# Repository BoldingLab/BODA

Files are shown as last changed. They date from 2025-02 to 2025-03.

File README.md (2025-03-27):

# BODA - Biosensor One-photon Data Acquisition

<p align="center">
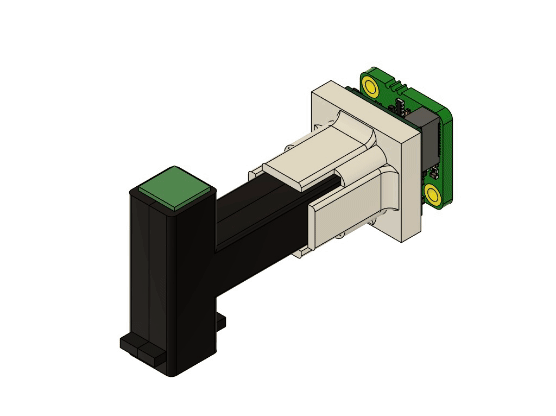
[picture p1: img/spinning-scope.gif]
Dual-Color Widefield Miniscope
  
</p>

## Overview

This repository contains design files, assembly instructions, and software for a high-resolution dual-color widefield miniscope optimized for fluorescence imaging in freely moving mice. The design features improved optical performance through the use of achromatic doublets and a refined optical path that provides:

- 2.45× magnification (increased from 0.9× in previous designs)
- 2.0mm minimum field of view
- Significantly reduced chromatic aberration
- Enhanced excitation light focusing
- Modular CMOS mount for flexible sensor options

## Repository Structure

```
.
├── assembly/               # Step-by-step assembly instructions
│   ├── Optical-Component-Assembly.md
│   ├── CMOS-Assembly.md
│   ├── LED-Installation.md
│   └── Resin-Print-Post-Processing.md
├── data-acquisition/       # Software for image acquisition
│   ├── data-acquisition.py
│   ├── DAC-README.md
│   └── Napari-Micromanager-DAC.md
├── img/                    # Images and figures
├── Optical-Analysis/       # Optical design analysis
│   ├── emission-system.ipynb
│   ├── excitation-system.ipynb
│   └── lens-data/
├── procurement/            # Bill of materials and sourcing information
└── README.md               # This file
```

## Optical Design

The miniscope uses a precisely calculated optical arrangement to achieve high-quality fluorescence imaging with minimal aberrations:

- **Emission Path**: Three achromatic doublets arranged to maximize resolution while maintaining a 2.0mm FOV
- **Excitation Path**: Two plano-convex lenses to optimize LED illumination
- **Filters**: 59022m emission filter and 59022x excitation filter, with a custom dichroic mirror

The design prioritizes:
1. High native resolution through increased magnification
2. Minimal chromatic aberration using achromatic doublets
3. Efficient excitation light delivery
4. Compact, lightweight form factor (under 4.5g)

## Assembly Process

Follow these steps to build your own miniscope:

1. **3D Printing**: Use the provided STL files to print the housing components using a high-resolution resin printer
2. **Post-Processing**: Clean and cure the printed parts following the [post-processing guide](assembly/Resin-Print-Post-Processing.md)
3. **Optical Assembly**: Install the optical components following the [optical assembly guide](assembly/Optical-Component-Assembly.md)
4. **LED Installation**: Set up the excitation system using the [LED installation guide](assembly/LED-Installation.md)
5. **CMOS Installation**: Prepare and install the camera module using the [CMOS assembly guide](assembly/CMOS-Assembly.md)

## Data Acquisition

Two options are provided for image acquisition:

1. **Simple Python GUI** - A lightweight application for controlling XIMEA cameras with features for:
   - Live viewing
   - Recording
   - Single frame capture
   - Adjustable exposure and downsampling

2. **Napari-Micromanager Integration** - A more advanced option providing:
   - Multi-dimensional acquisition
   - Integration with other microscopy hardware
   - Advanced image analysis capabilities

Setup and usage instructions can be found in the [data-acquisition](data-acquisition/) directory.

## Part Procurement

A complete list of components needed to build the miniscope can be found in the [procurement](procurement/) directory, including:
- Optical components
- Camera components
- Excitation components
- Housing components
- Assembly tools

## Optical Performance

This design offers significant improvements over previous miniscope implementations:
- **Magnification**: Increased from 0.9× to 2.45× (172% improvement)
- **Resolution**: Improved by 2.72× while maintaining a minimum 2.0mm FOV
- **Chromatic Aberration**: Reduced by >167%, eliminating the need to reposition when switching between red and green channels

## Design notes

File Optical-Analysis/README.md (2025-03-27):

# Dual-Color Widefield Miniscope Optical Design Overview

## I. Objective
Achieve the highest possible image quality in the dual-channel miniscope while maintaining a minimum field of view (FOV) of 2.0 millimeters.

## II. Methods
Various optical simulation software was developed in Python and used Zemax OpticStudio to simulate the optical components in the miniscope in order to optimize the optics configuration for the objective. Only one method of increasing native image resolution within the current system was determined to be feasible: Increasing the magnification of the miniscope. However, increasing the magnification of an optical system also comes with the caveat of decreasing the FOV of the optical system so a balance must be struck for the design.

To increase the magnification of the miniscope, the most important factors for increasing magnification are the distance between the object plane and the first lens of the system and the properties of the individual lenses.

Other than the resolution, another problem with the previous models of miniscope is the significant amount of noise and chromatic aberration in its images. The solution to mitigate most of the aberration issues is to replace the plano-convex lenses in the previous designs with doublets. Moreover, the image quality can also be improved by increasing the intensity of the excitation light due to its interaction with the fluorescence in the cells that the miniscope is designed to capture.

### External Constraints
There are four main external constraints for the miniscope that the optical system must also abide to:
- Weight of the miniscope
- Center of mass of the miniscope
- Availability of optical components
- Cost of optical components

Due to the fact that the miniscope is designed to mount the head of a mouse, the weight of the miniscope has to remain under 4.5 grams. As such, the optical components that are used for the miniscope must also account for this factor. Notably, lenses with an increased diameter exponentially increase the weight of the system due to the necessity of increasing the dimension of the entire miniscope housing to accommodate such a change. After experimentations with lenses with a diameter up to 9mm, it was concluded that using any optical component with a diameter above 6mm would make it extremely challenging to fulfill this constraint.

The center of mass of the miniscope must also be considered to account for how it might affect the mice that the miniscope will be mounted on. While this metric was never defined quantitatively during the duration of the project, it was determined that it would be too risky to have a "tall" miniscope where the emission portion of the miniscope is directly above the object plane, even if it would slightly improve the image quality by not requiring the image to be reflected. The availability of off-the-shelf lenses as well as the cost of each optical component was also considered during the design process to ensure that the miniscope can be replicated in the future at a reasonable cost.

## III. Final Design
After numerous tests with different simulations and designs, the miniscope design was finalized and the most notable changes from the original designs are:
- Replaced the plano-convex lenses with doublets
- Moved the initial lens directly above the object plane, placing it significantly closer than before
- Increased the magnification of the system
- Increased the intensity of the excitation light by increasing focus of the LED light
- Modularized the CMOS mount of the miniscope, allowing for different CMOS to be used for the same miniscope
- Removed one dichroic mirror from the design, mirroring the captured image as a side effect

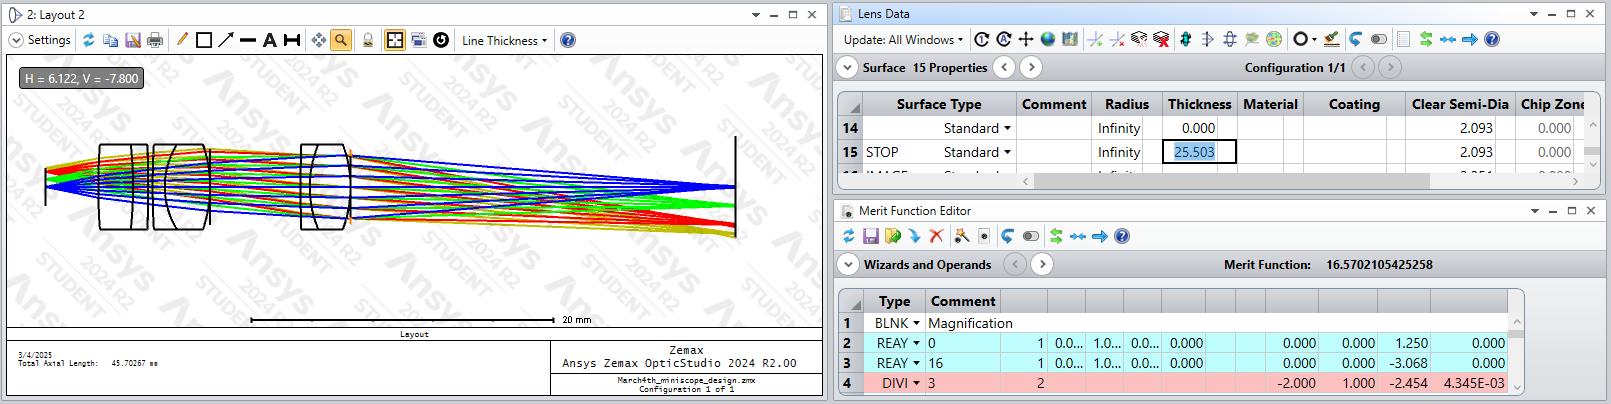
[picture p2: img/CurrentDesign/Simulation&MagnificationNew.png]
Figure 1: A simulation of the emission system of the miniscope in Zemax. The tables on the upper right lists each optical component within the system as well as the distance between. The table on the lower right showcases the magnification of the system.

Figure 1: A simulation of the emission system of the miniscope in Zemax. The tables on the upper right lists each optical component within the system as well as the distance between. The table on the lower right showcases the magnification of the system.
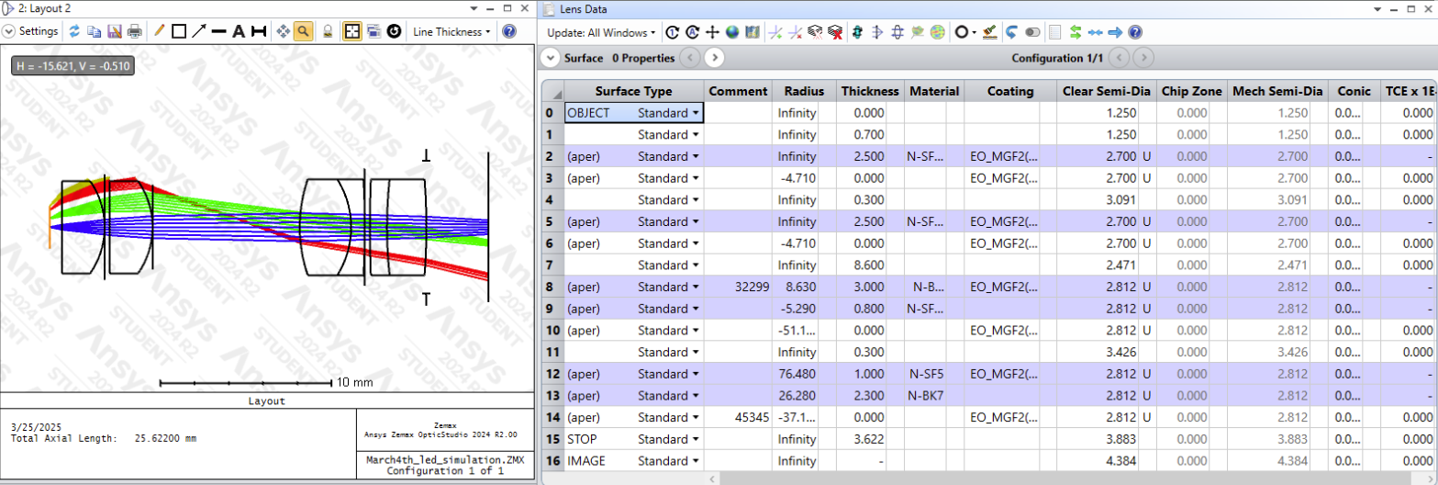
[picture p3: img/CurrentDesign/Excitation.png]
Figure 3: A simulation of the excitation system of the miniscope in Zemax. The tables on the upper right lists each optical component within the system as well as the distance between.

Figure 2: A simulation of the excitation system of the miniscope in Zemax. The tables on the upper right lists each optical component within the system as well as the distance between.
## IV. Results
The new design of the miniscope successfully achieved the objective of the project and tackled the numerous challenges the previous design had. The current design is able to produce higher quality images by improving the image resolution, reducing chromatic aberration, and increasing the effectiveness of excitation.

### Image Resolution
As mentioned above, image resolution directly correlates with the magnification of the system. By placing the lenses of the system closer to the object plane and selecting the proper lenses, the magnification of the optical system increased from 0.9x to 2.45x, resulting in a resolution increase and FOV decrease by the same magnitude of 2.72x theoretically (value obtained by dividing 2.45 by 0.9).

The theoretical magnification of the image is calculated using the "Merit Function Editor" function in Zemax, as seen in Figure 2. To calculate the magnification, the "REAY" values (y-coordinate of a simulated light ray) at the object and image plane were extracted, denoted by the values 0 and 15 respectively on the table. Afterwards, the values were divided by each other using the following equation to obtain the magnification.

```
Magnification = REAY_Image / REAY_Object
```

The logic behind the calculation being that as an image is being magnified, individual light rays will land farther from the center point than they were originally, resulting in every light ray spreading out from the center point and resulting in a larger image. By capturing the position of the rays, we can calculate how much an image is magnified by calculating how much it deviated from the original coordinate.

### Chromatic Aberration
By replacing the plano-convex lenses with doublets, the significant chromatic aberration issues that the previous design suffered from were also almost mostly mitigated. The most significant effect of this improvement is eliminating the need to reposition the y-axis of the miniscope when switching between red and green channels when performing the relevant experiments. This improvement allowed for both channels to be captured with high native resolution when it is placed in a fixed position atop a mouse.

<table>
  <tr>
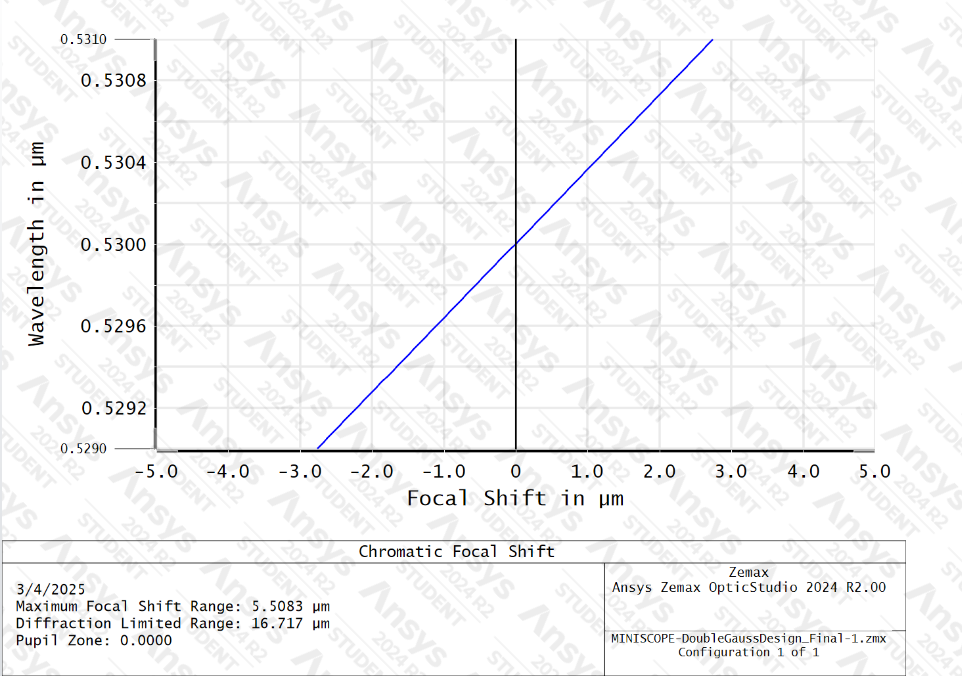
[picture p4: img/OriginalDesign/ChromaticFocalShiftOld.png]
    <td></td>
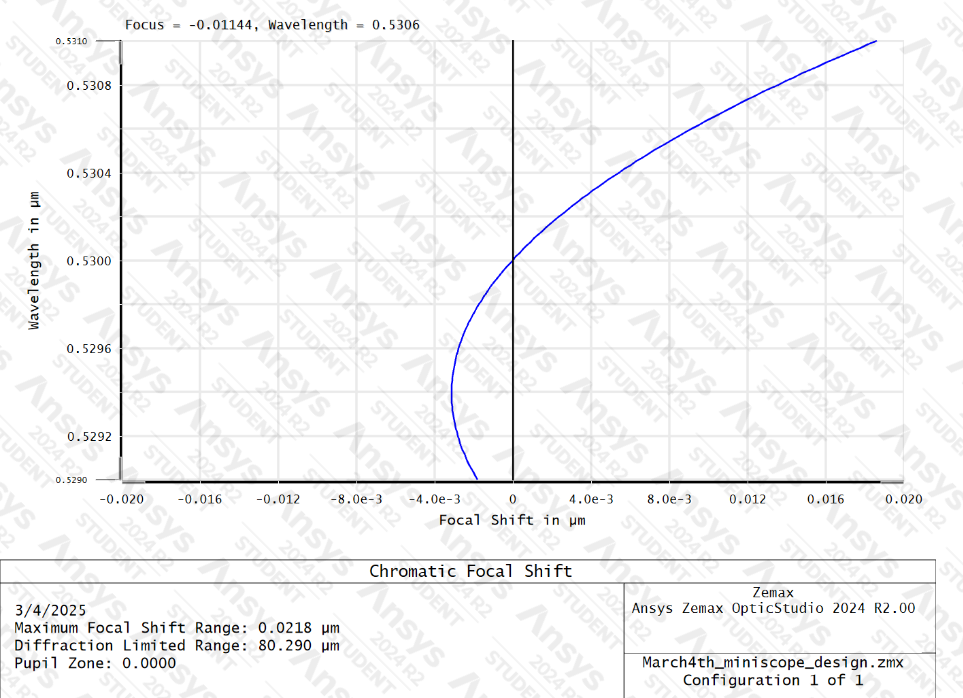
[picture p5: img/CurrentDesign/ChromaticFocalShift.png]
    <td></td>
  </tr>
</table>
Figure 4: Comparison of chromatic aberration between the old design (left) and the new design (right) in Zemax. The chromatic aberration of the new design is significantly reduced as seen in the values on the x-axis of the graphs.

As shown in the first graph representing the old design, the focal shift of the image linearly shifts roughly 1μm for every wavelength shift of 0.0004μm. Considering the peak wavelength of each channel has a difference of roughly 0.08μm, it would mean that that we would need to shift the y-coordinate of the miniscope by 0.08μm/0.0004μm = 200μm every time a channel is switched in the old design, which aligns with what was observed experimentally. By comparison, the same wavelength shift of 0.0004μm in the new design results in a focal shift of less than 0.006μm in a non-linear parabolic trend, essentially reducing the effect of the chromatic aberration by more than 167%.

However, it should be noted that the new design performs slightly worse in some of the other aberration tests in Zemax, in categories such as field curvature, grid distortion, longitude aberration etc.

<table>
  <tr>
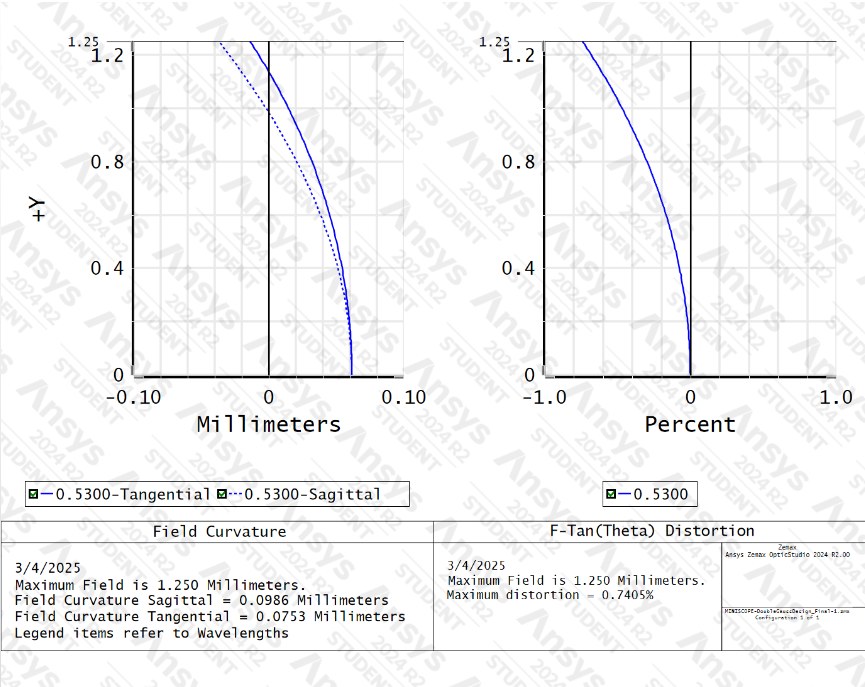
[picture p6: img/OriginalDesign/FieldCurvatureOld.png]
    <td></td>
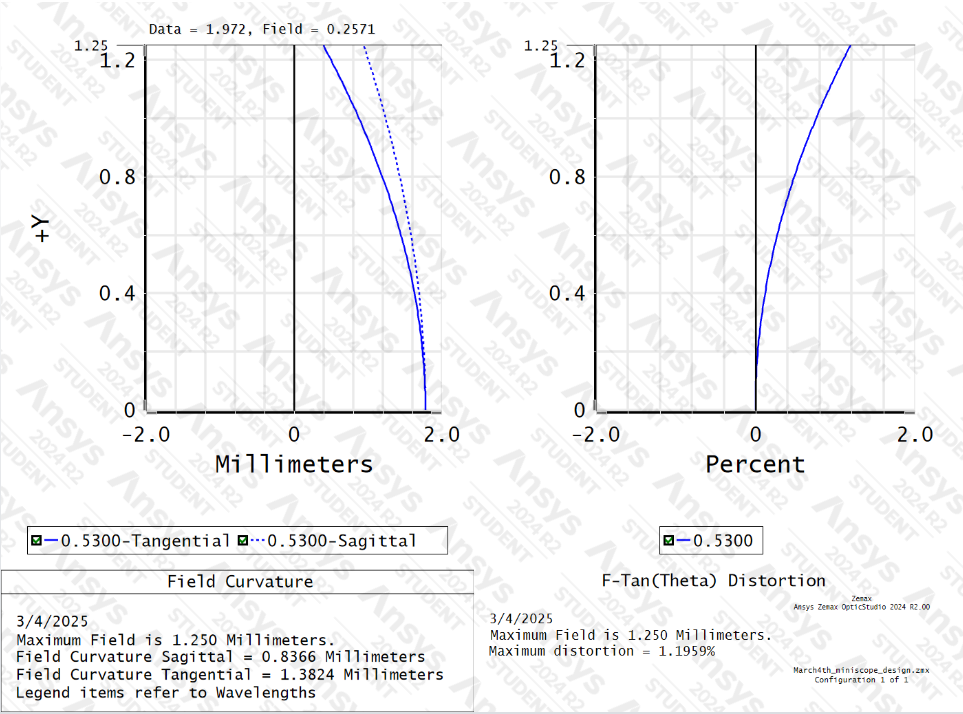
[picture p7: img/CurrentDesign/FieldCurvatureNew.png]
    <td></td>
  </tr>
</table>
Figure 5: Comparison of field curvature between the old design (left) and the new design (right) in Zemax.

Notably the field curvature sagittal and tangential values of the old design increased from 0.0986mm and 0.0753mm respectively to 0.8366mm and 1.3824mm in the new design. The effect of these aberrations could not be observed by eye experimentally and it is not clear how much effect this has on image quality.

### Excitation
The effectiveness of the excitation was significantly improved by better focusing the LED light on the object. This was accomplished by using two plano-convex lenses in the excitation tower instead of one. Notably, this is the same lens used in the original design and the only change is the increase of quantity. Different lenses in different quantities were also considered but it was determined that three lenses would increase the focus too much, resulting in the excitation area on the object becoming too small. A suitable lens in Zemax that could replace the two-lens configuration with one single lens could not be found so the current design with two lenses is determined to be the best option at the time.

## V. Conclusion
The miniscope's performance and functionality were significantly optimized and improved upon with the changes brought about by the redesign. This report didn't address the filters components of the miniscope because they remain the same as the previous design and attempts at changing those components did not yield significant results. Should changes in magnification be needed in the future, the easiest method is to swap out the doublets, particularly the 15FL doublet. However, the position of the image plane, or the CMOS, would also need to be adjusted, since magnification positively correlates with focal length.

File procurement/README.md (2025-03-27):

# Procurement Guide

## Optical Components
| Item # | Component Description | Quantity | Function | Part Number/Model | Supplier Link |
|---|---|---|---|---|---|
| O1 | 6.0mm Dia x 6.0mm FL Plano-Convex Lens | 2 | LED focusing for excitation system | #45-078 | [Edmund Optics](https://www.edmundoptics.com/p/60mm-dia-x-60mm-fl-mgfsub2sub-coated-plano-convex-lens/5569/) |
| O2 | 6.25mm Dia x 15mm FL Achromatic Doublet | 1 | Emission path imaging | #32-301 | [Edmund Optics](https://www.edmundoptics.com/p/625mm-dia-x-15mm-fl-mgfsub2sub-coated-achromatic-doublet-lens/2272/) |
| O3 | 6.25mm Dia x 12.5mm FL Achromatic Doublet | 1 | Emission path imaging | #32-299 | [Edmund Optics](https://www.edmundoptics.com/p/625mm-dia-x-125mm-fl-mgfsub2sub-coated-achromatic-doublet-lens/2271/) |
| O4 | 6.25mm Dia x 60mm FL Achromatic Doublet | 1 | Emission path imaging | #45-345 | [Edmund Optics](https://www.edmundoptics.com/p/625mm-dia-x-60mm-fl-mgfsub2sub-coated-achromatic-doublet-lens/5815/) |
| O5 | Emission Filter | 1 | Filtering emission light | 59022m | [Chroma](https://www.chroma.com/products/parts/59022m) |
| O6 | Dichroic Filter | 1 | Splitting excitation and emission paths | CT455/556/664rpc | Custom Order from [Chroma](https://www.chroma.com/contact) |
| O7 | Excitation Filter | 1 | Filtering excitation light | 59022x | [Chroma](https://www.chroma.com/products/parts/59022x) |

## Camera Components
| Item # | Component Description | Quantity | Function | Part Number/Model | Supplier Link |
|---|---|---|---|---|---|
| C1 | MU196MR-ON CMOS Camera | 1 | Image sensor for emission path | MU196MR-ON | [Ximea](https://www.ximea.com/products/miniature-compact/ximu-smallest-industrial-usb-cameras/onsemi-ar2020-usb3-mono-ximu-smallest-camera) |
| C2 | MU9 CMOS Camera (alternative) | 1 | Alternative image sensor | MU9 | [Ximea](https://www.ximea.com/products/subminiature-cameras) |
| C3 | ADPT-MU-CX3 Camera Adapter | 1 | Adapter for MU196 Camera | ADPT-MU-CX3 | [Ximea](https://www.ximea.com/support/wiki/camerase/ADPT-MU-CX3) |
| C4 | Camera module coax adapter | 1 | Breakout board for USB3 cameras | BOB-MQ-FL | [Ximea](https://www.ximea.com/accessories/adapterboards/breakout-board-and-gpio-for-usb3-cameras) |
| C5 | USB3 Micro coax cable | 1 | Camera connection | USB3-MRB-0.25 | [Ximea](https://www.ximea.com/accessories/cables/usb3-micro-coax-cable-25-cm) |
| C6 | CMOS specific printed mount | 1 | Housing for camera module | Custom 3D Print | Internal Production |

## Excitation Components
| Item # | Component Description | Quantity | Function | Part Number/Model | Supplier Link |
|---|---|---|---|---|---|
| E1 | LED PCB | 1 | Power LED system | Custom PCB | Internal Production |
| E2 | Blue LED (460nm - 480nm) | 1 | GFP/FITC excitation | LXZ1-PB01 | [Mouser](https://www.mouser.com/ProductDetail/Lumileds/LXZ1-PB01?qs=7Vwje68bFtP7mJVEHF0omw%3D%3D) |
| E3 | Lime/Green LED (566nm - 569nm) | 1 | mCherry/RFP excitation | LXZ1-PX01 | [Mouser](https://www.mouser.com/ProductDetail/Lumileds/LXZ1-PX01?qs=W988lRlZNbIugD4h8%2FoCRA%3D%3D) |
| E4 | Cyan LED (490nm - 510nm) | 1 | Alternative excitation (optional) | LXZ1-PE01 | [Mouser](https://www.mouser.com/ProductDetail/Lumileds/LXZ1-PE01?qs=7Vwje68bFtOXkijd79%2FPBQ%3D%3D) |
| E5 | Soldering supplies | 1 set | LED assembly | - | Local Supplier |
| E6 | Black/Opaque electrical tape | 1 roll | Light isolation | - | Local Supplier |
| E7 | Wiring for LED connections | 1 set | Power connections | AWG28-30 | Local Supplier |

## Housing Components
| Item # | Component Description | Quantity | Function | Part Number/Model | Supplier Link |
|---|---|---|---|---|---|
| H1 | Main body | 1 | House all optical components | Custom 3D Print | Internal Production |
| H2 | Lid body | 1 | Seal internal components | Custom 3D Print | Internal Production |
| H3 | Black paint | 1 | Interior light isolation | Matte Black | Local Supplier |
| H4 | Optical adhesive | 1 | Secure components | NOA61 or similar | [Thorlabs](https://www.thorlabs.com/thorproduct.cfm?partnumber=NOA61) |

## Assembly Tools
| Item # | Component Description | Quantity | Function | Part Number/Model | Supplier Link |
|---|---|---|---|---|---|
| T1 | Small Phillips screwdriver | 1 | Camera assembly | - | Local Supplier |
| T2 | Lens cleaning materials | 1 set | Optical component cleaning | - | Local Supplier |
| T3 | Soldering iron | 1 | LED PCB assembly | - | Local Supplier |
| T4 | Solder paste | 1 | LED PCB assembly | - | Local Supplier |
| T5 | Forceps | 1 | Component handling | - | Local Supplier |
| T6 | Vise or clamp | 1 | Housing assembly | - | Local Supplier |

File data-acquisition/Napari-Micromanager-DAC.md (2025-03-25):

# Napari-Micromanager with Ximea Camera Setup Guide

## Prerequisites
- Windows computer with administrator privileges
- Python 3.8 or later
- Ximea camera hardware

## Quick Setup Steps

### 1. Install Napari-Micromanager
```bash
# Create environment
conda create -n napari-mm python=3.9
conda activate napari-mm

# Install napari and plugin
pip install "napari[all]"
pip install napari-micromanager
```

### 2. Install Ximea Software
1. Download the latest [XIMEA API Software Package](https://www.ximea.com/support/wiki/apis/XIMEA_API_Software_Package)
2. Run the installer, ensuring camera drivers are included
3. Test with Ximea CamTool to verify camera connection

### 3. Integrate Ximea with Micro-Manager
1. Locate `xiapi64.dll` in `C:\XIMEA\API\x64\`
2. Find your Micro-Manager directory:
   ```python
   python -c "from pymmcore_plus import find_micromanager; print(find_micromanager())"
   ```
3. Copy the DLL to the Micro-Manager directory

### 4. Generate Camera Configuration
1. Launch Micro-Manager directly from the installation directory
2. Select "Tools" > "Hardware Configuration Wizard"
3. Create new configuration, add "XIMEACamera" from device list
4. Complete wizard and save configuration file (e.g., `XimeaConfig.cfg`)
5. Test with "Snap" button to capture an image

### 5. Use in Napari
1. Launch napari
2. Go to Plugins > napari-micromanager
3. Load your Ximea configuration file
4. The camera should now be available for use

## Configuration File Usage
- Place the configuration file you'll receive in `[User Directory]/Documents/Micro-Manager/`
- Load via "File" > "Load System Configuration" in Micro-Manager
- Or specify when launching in Python:
  ```python
  import napari
  from napari_micromanager import MicroManagerWidget
  
  viewer = napari.Viewer()
  mm_widget = MicroManagerWidget(viewer)
  mm_widget.load_configuration("/path/to/your/ximea_config.cfg")
  ```

## Troubleshooting
- If camera isn't detected, verify DLL is correctly placed
- For communication issues, check camera connections and test with Ximea CamTool
- If using older Micro-Manager (pre-2018), rename xiapi64.dll to m3apiX64.dll

## Resources
- [Napari-Micromanager Repository](https://github.com/pymmcore-plus/napari-micromanager)
- [Micro-Manager Documentation](https://micro-manager.org/Micro-Manager_User%27s_Guide)
- [Ximea Camera in Micro-Manager](https://micro-manager.org/XIMEA)

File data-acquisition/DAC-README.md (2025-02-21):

# Camera Control Application

A Python-based GUI application for controlling XIMEA cameras with features for live viewing, recording, and image capture.

## Prerequisites

### Required Hardware
- XIMEA camera (compatible with xiapi)
- USB3 port for camera connection

### Required Software
- Python 3.7 or higher
- pip (Python package installer)

## Installation

1. **Create a Virtual Environment** (recommended)
   ```bash
   python -m venv venv
   
   # Activate on Windows
   venv\Scripts\activate
   
   # Activate on macOS/Linux
   source venv/bin/activate
   ```

2. **Install Required Packages**
   ```bash
   pip install customtkinter
   pip install tkinterDnD
   pip install opencv-python
   ```

3. **Install XIMEA Software Package**
   - Download and install XIMEA Software Package (xiAPI) from the [XIMEA website](https://www.ximea.com/support/documents/4)
   - Follow XIMEA's installation guide for your operating system
   - Install the Python API:
     ```bash
     pip install ximea
     ```

## Application Features

### Camera Settings
- Adjustable exposure time
- Multiple downsampling options (None, 1/2, 1/4, 1/8)
- Zoom levels (None, 2x, 3x, 7x, 10x)
- FPS display toggle
- Timer display toggle

### Recording Options
- Custom recording name
- Video recording (.avi format)
- Single frame capture (PNG format)
- Live preview window

## Usage

1. **Starting the Application**
   ```bash
   python camera_control.py
   ```

2. **Basic Operation**
   - Enter a recording name (optional - defaults to 'recording')
   - Set exposure time (optional - defaults to 80000)
   - Select desired downsampling rate
   - Select zoom level if needed
   - Toggle timer/FPS display as needed
   - Click "Start" to begin camera feed
   - Use "Take Photo" for single frame capture
   - Click "Stop" to end recording

### Main Controls
- **Start Button**: Initiates camera feed and recording
- **Stop Button**: Ends camera feed and saves recording
- **Take Photo**: Captures current frame as PNG file

### Recording Settings
- Files are saved in the working directory
- Videos are saved as .avi files using MJPG codec
- Photos are saved as PNG files with timestamp

## Troubleshooting

### Common Issues
1. **Camera Not Detected**
   - Ensure camera is properly connected via USB3
   - Verify XIMEA drivers are installed
   - Check camera permissions on your system

2. **Recording Issues**
   - Ensure sufficient disk space
   - Verify write permissions in working directory
   - Check if previous recording was properly closed

3. **Display Issues**
   - Ensure OpenCV is properly installed
   - Check monitor resolution settings
   - Verify GUI framework dependencies

## File Naming Convention

- Videos: `{recording_name}.avi`
- Photos: `{recording_name}_{YYYYMMDD-HHMMSS}.png`

## Notes

- Application window size: 620x480 pixels
- Live preview window: 1296x972 pixels
- Default recording name: "recording"
- Default exposure: 80000
- Video frame rate: 4.6 FPS

## System Requirements

- Operating System: Windows/Linux/macOS
- RAM: 4GB minimum (8GB recommended)
- USB3 port
- Sufficient storage space for recordings

---

*For additional support or issues, please refer to the XIMEA documentation or contact technical support.*

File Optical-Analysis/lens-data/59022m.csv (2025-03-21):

300 | 9.9999999392253E-09
301 | 9.9999999392253E-09
302 | 5.5039902235876E-07
303 | 8.0143399827648E-07
304 | 9.9999999392253E-09
305 | 1.1956800562984E-06
306 | 8.9174000095227E-07
307 | 2.4306498858095E-07
308 | 7.2598800215928E-07
309 | 2.4084800998025E-07
310 | 3.4971898799085E-07
311 | 3.5180599411433E-07
312 | 5.8330800811746E-07
313 | 3.5065698966719E-07
314 | 2.6826700860738E-08
315 | 8.8783099272405E-07
316 | 9.9999999392253E-09
317 | 4.868559813076E-07
318 | 7.8577397744084E-07
319 | 7.5280598821337E-07
320 | 2.6719499146566E-07
321 | 9.9999999392253E-09
322 | 4.1348300783284E-07
323 | 9.3544201718032E-07
324 | 1.0675800012905E-06
325 | 1.0479600405233E-06
326 | 4.6503100747941E-07
327 | 1.9058599320942E-07
328 | 2.8124298978582E-07
329 | 3.0522599558935E-07
330 | 9.8618897936831E-07
331 | 7.0249200234684E-07
332 | 9.9999999392253E-09
333 | 6.9148200054769E-07
334 | 3.7096299365658E-07
335 | 3.3522699283139E-08
336 | 6.9079499098734E-07
337 | 1.7073399760648E-07
338 | 3.5456798741507E-07
339 | 7.0355298475988E-07
340 | 1.0838499520105E-06
341 | 4.0019199332164E-07
342 | 6.8467801384031E-07
343 | 1.0458300039318E-06
344 | 9.0532597596393E-07
345 | 2.8010600772177E-07
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

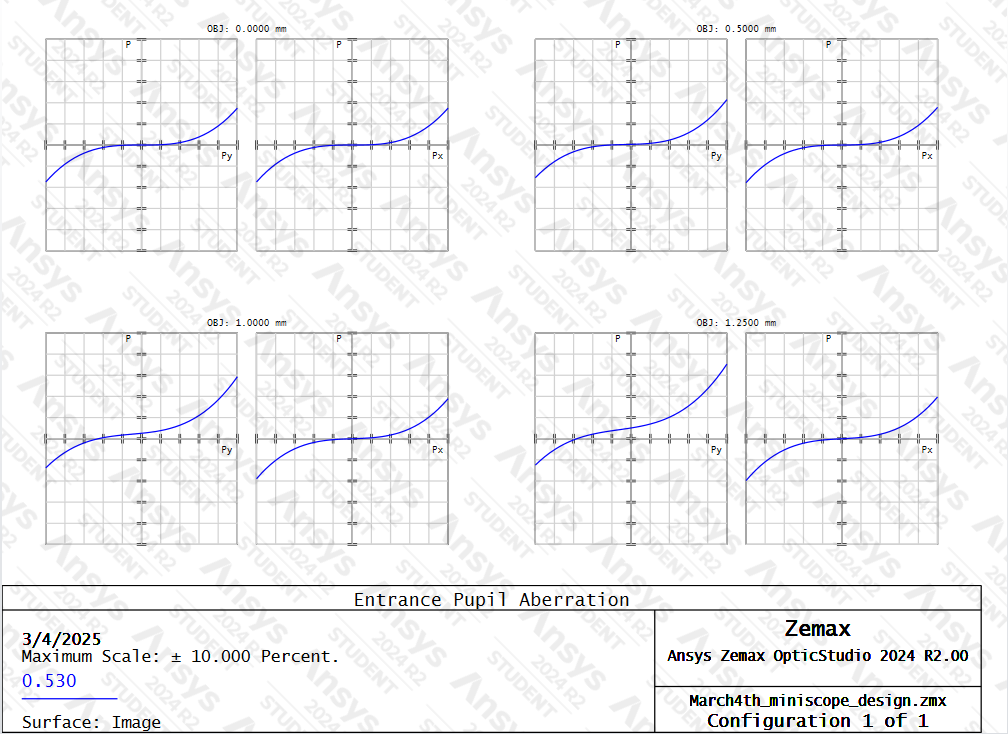
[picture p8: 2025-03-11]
img/CurrentDesign/Pupil Abberation New.png

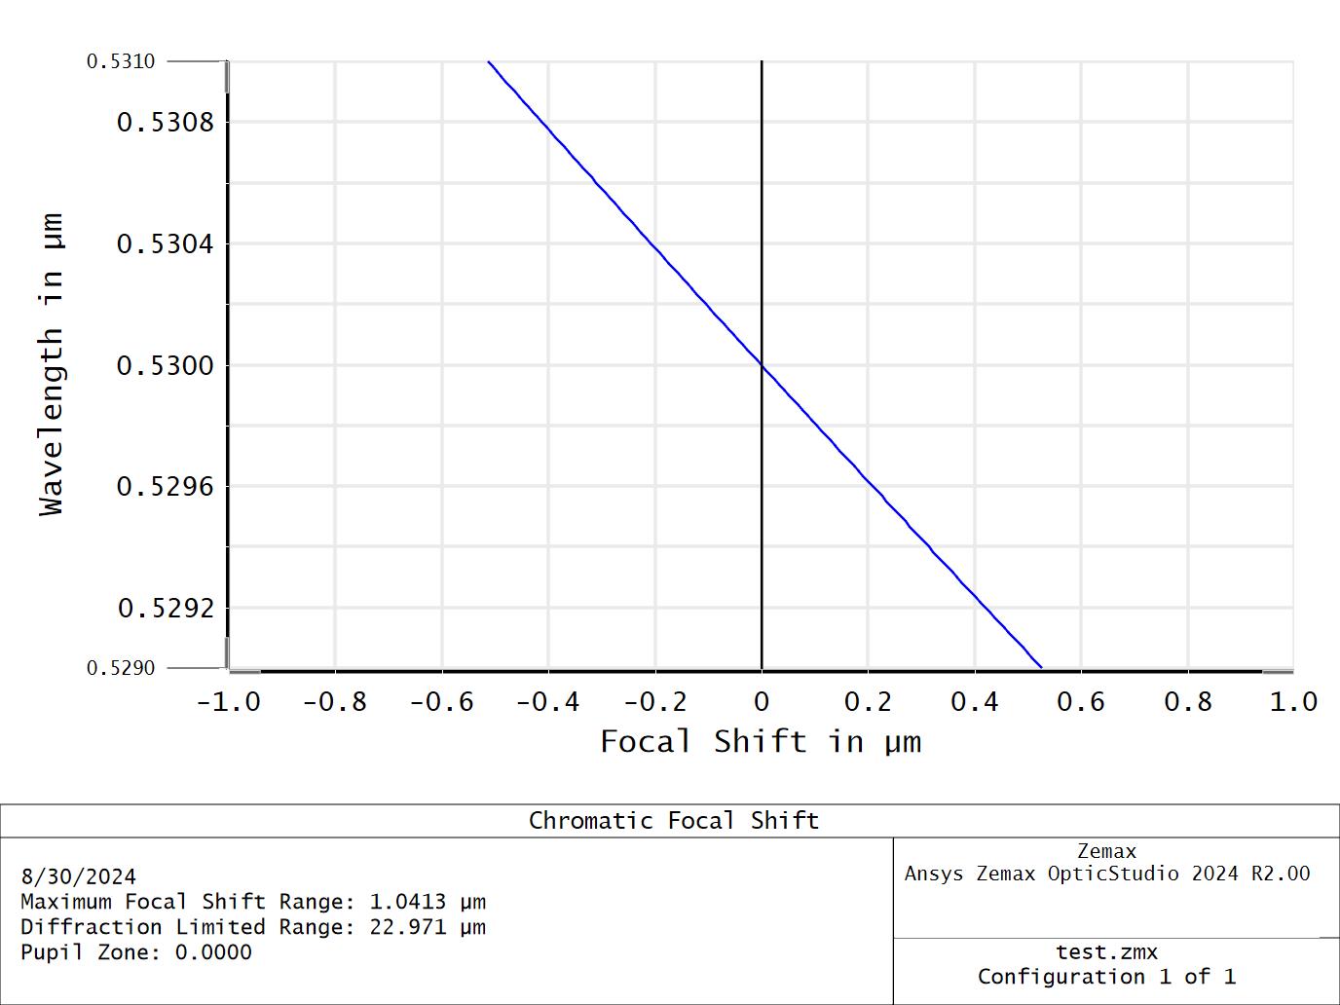
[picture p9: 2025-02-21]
Zemax/Zemax Files/Images/redesign_focalshift.jpg

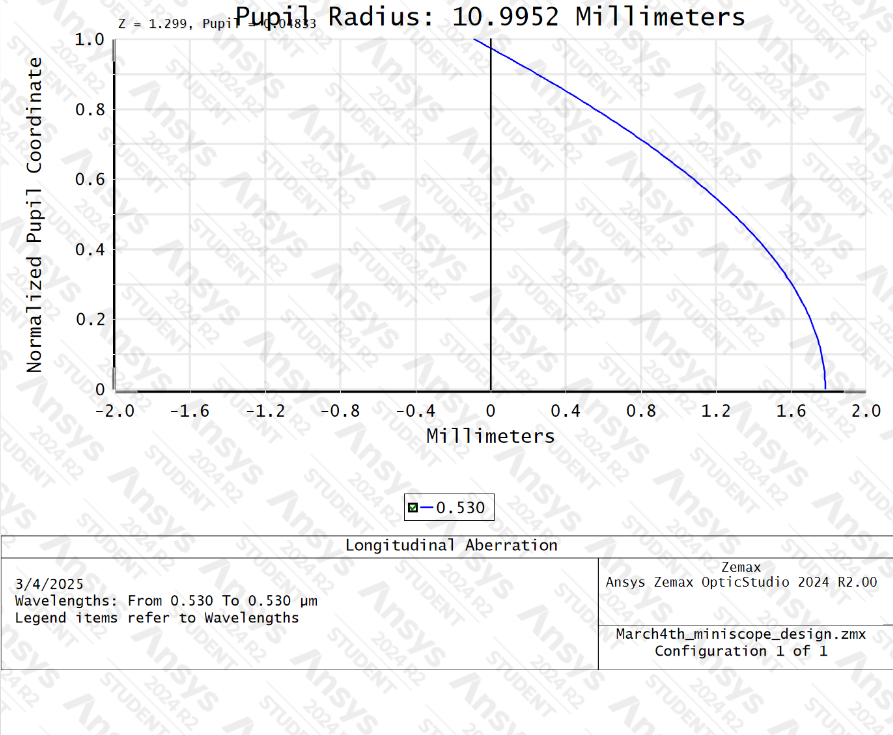
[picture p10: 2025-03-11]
img/CurrentDesign/Longtitude Abberation New.png

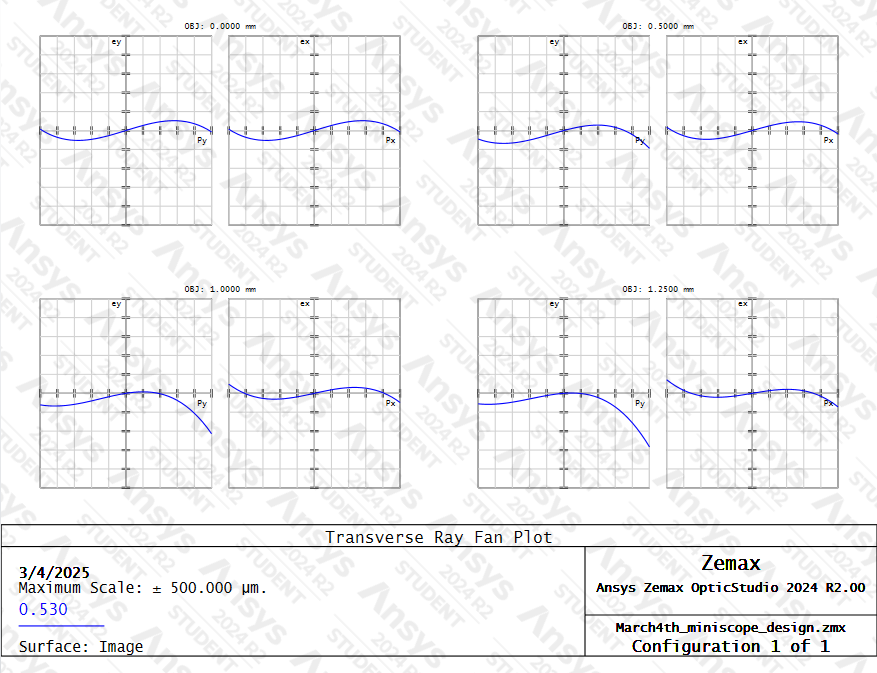
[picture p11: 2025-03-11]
img/CurrentDesign/Ray Abberation New.png

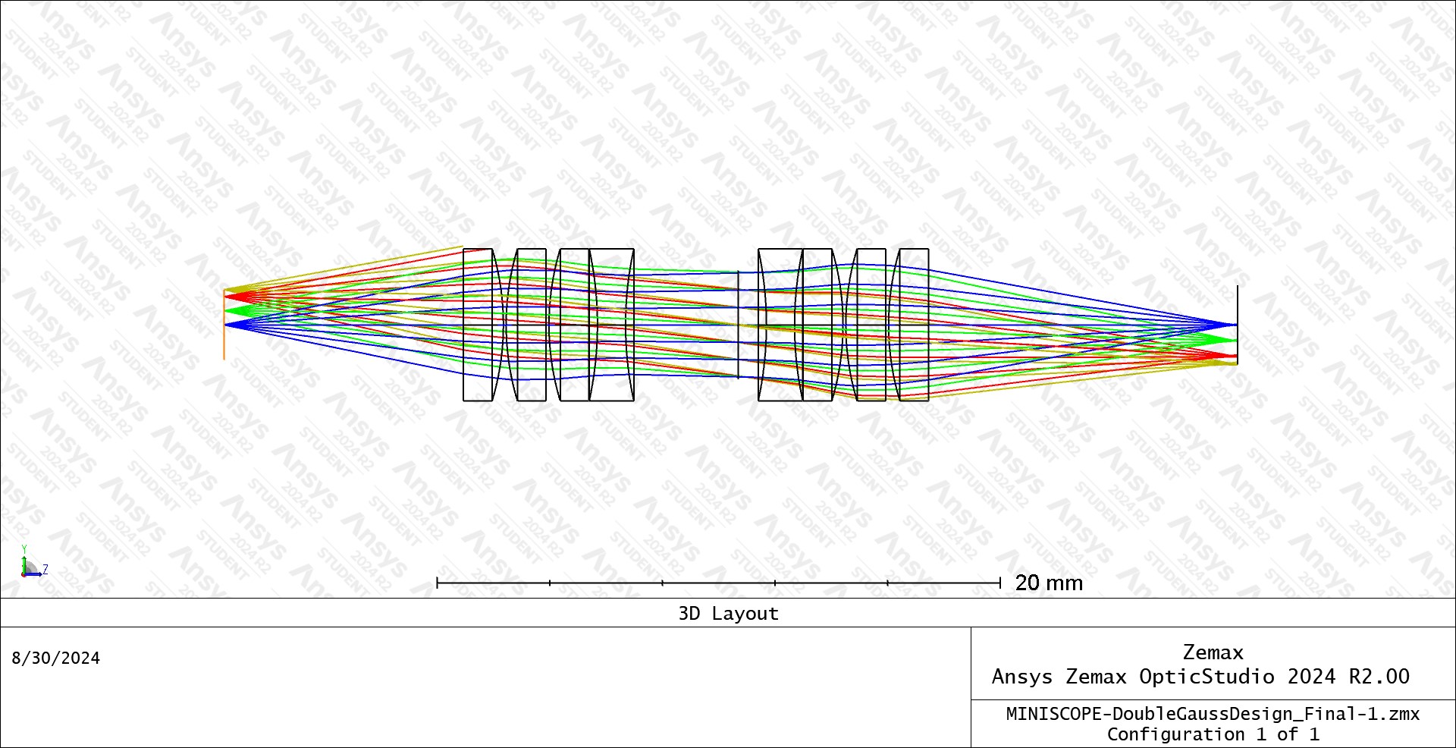
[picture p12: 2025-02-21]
Zemax/Zemax Files/Images/original_design_zemax.jpg

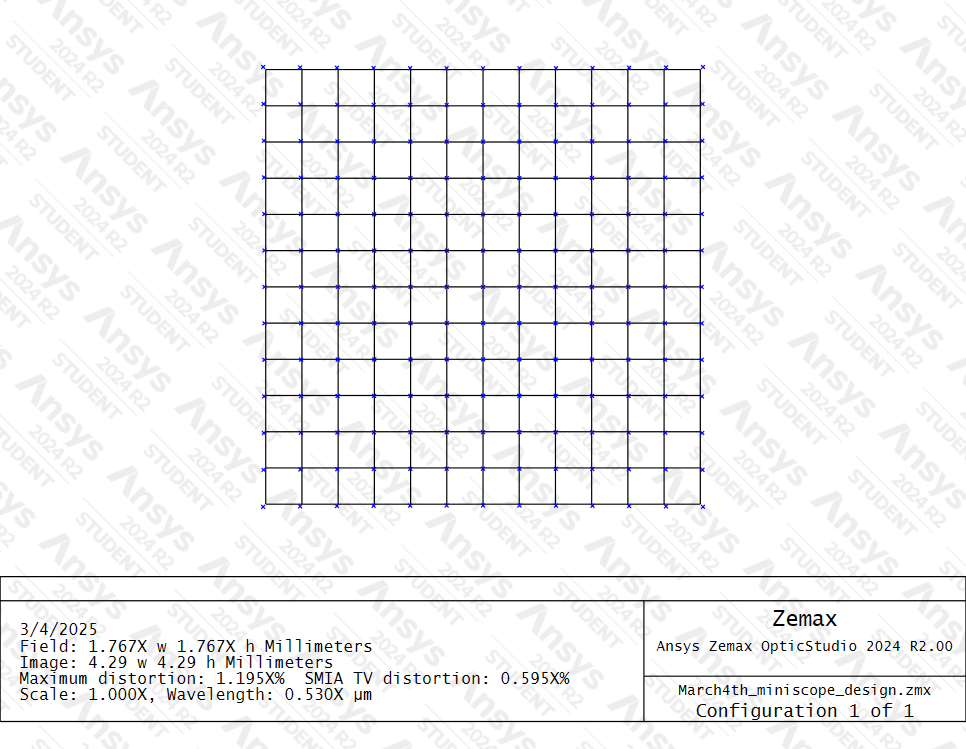
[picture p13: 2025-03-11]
img/CurrentDesign/Grid Distortion New.png

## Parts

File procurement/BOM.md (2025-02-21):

# Bill of Materials

## Optical Components
| Item # | Component Description | Quantity | Function | Part Number/Model | Supplier Link |
|---|---|---|---|---|---|
| O1 | 6.0mm Dia x 6.0mm FL Plano-Convex Lens | 2 | LED collimation | - | [Edmund Optics](https://www.edmundoptics.com/p/60mm-dia-x-60mm-fl-mgfsub2sub-coated-plano-convex-lens/5569/) |
| O2 | 6.25 Dia x 15mm FL Doublet | 1 | Magnifying and focusing image | - | [Edmund Optics](https://www.edmundoptics.com/p/625mm-dia-x-15mm-fl-mgfsub2sub-coated-achromatic-doublet-lens/2272/) |
| O3 | 6.25 Dia x 12mm FL Doublet | 1 | Magnifying and focusing image | - | [Edmund Optics](https://www.edmundoptics.com/p/625mm-dia-x-125mm-fl-mgfsub2sub-coated-achromatic-doublet-lens/2271/) |
| O4 | 6.25 Dia x 60mm FL Doublet | 1 | Magnifying and focusing image | - | [Edmund Optics](https://www.edmundoptics.com/p/625mm-dia-x-60mm-fl-mgfsub2sub-coated-achromatic-doublet-lens/5815/) |
| O5 | Emission Filter (new design) | 1 | Filtering out noise from emission | ZET488/561m | [Chroma](https://www.chroma.com/products/parts/zet488-561m) |
| O6 | Emission Filter (previous design) | 1 | Filtering out noise from emission | 59022m | [Chroma](https://www.chroma.com/products/parts/59022m) |
| O7 | Dichroic Filter | 1 | Allowing excitation light to pass through while reflecting emission light | CT455/556/664rpc | Custom Order |
| O8 | Excitation Filter (new design) | 1 | Filtering out noise from excitation | ZET488/561x | [Chroma](https://www.chroma.com/products/parts/zet488-561x) |
| O9 | Excitation Filter (previous design) | 1 | Filtering out noise from excitation | 59022x | [Chroma](https://www.chroma.com/products/parts/59022x) |

### Emission Components
| Item # | Component Description | Quantity | Function | Part Number/Model | Supplier Link |
|---|---|---|---|---|---|
| A1 | MU196MR-ON | 1 | Camera module | - | [Ximea](https://www.ximea.com/products/miniature-compact/ximu-smallest-industrial-usb-cameras/onsemi-ar2020-usb3-mono-ximu-smallest-camera) |
| A2 | Camera module coax adapter | 1 | Breakout board and GPIO for USB3 cameras | BOB-MQ-FL | [Ximea](https://www.ximea.com/accessories/adapterboards/breakout-board-and-gpio-for-usb3-cameras) |
| A3 | USB3 Micro coax cables | 1 | USB 3.1 Gen1 Micro-Coaxial cables | - | [Ximea](https://www.ximea.com/accessories/cables/usb3-micro-coax-cable-25-cm) |

## Excitation Components
| Item # | Component Description | Quantity | Function | Part Number/Model | Supplier Link |
|---|---|---|---|---|---|
| X1 | Emission PCB | 1 | Power LED system | - | - |
| X2 | Blue LED (460nm - 480nm) | 1 | Light source | lxz1-pb01 | [Mouser](https://www.mouser.com/ProductDetail/Lumileds/LXZ1-PB01?qs=7Vwje68bFtP7mJVEHF0omw%3D%3D) |
| X3 | Lime LED (566nm - 569nm) | 1 | Light source | lxz1-px01 | [Mouser](https://www.mouser.com/ProductDetail/Lumileds/LXZ1-PX01?qs=W988lRlZNbIugD4h8%2FoCRA%3D%3D) |
| X5 | Cyan LED (490nm - 510nm) | 1 | Light source | LXZ1-PE01 | [Mouser](https://www.mouser.com/ProductDetail/Lumileds/LXZ1-PE01?qs=7Vwje68bFtOXkijd79%2FPBQ%3D%3D) |

## Housing Components
| Item # | Component Description | Quantity | Function | Part Number/Model | Supplier Link |
|---|---|---|---|---|---|
| Y1 | Main body | 1 | house all components | - | - |
| Y2 | Lid body | 1 | Seal internal components in complete housing structure | - | - |

## Cost Summary by Section
| Section | Number of Components | Notes |
|---|---|---|
| Optical Components | - | To be specified |
| Emission Components | - | To be specified |
| Excitation Components | - | To be specified |
| Housing Components | - | To be specified |

*Notes:*
1. All quantities listed are minimum required quantities
2. The dichroic filter requires custom ordering
3. Both new and previous design filters are listed - verify which version is needed for your application
4. Exact costs are not included as prices may vary by supplier and quantity
5. Housing components section needs to be populated with required components
6. Contact suppliers for current pricing and availability
7. Some components may have minimum order quantities not reflected in this BOM

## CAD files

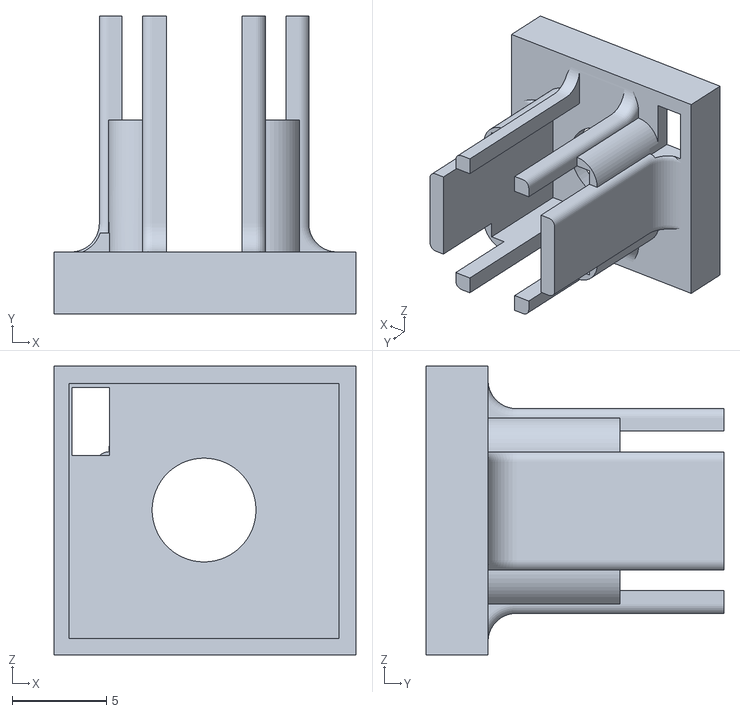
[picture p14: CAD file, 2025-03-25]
3D model/MU9-Holder.stl
16.0 x 15.8 x 15.3

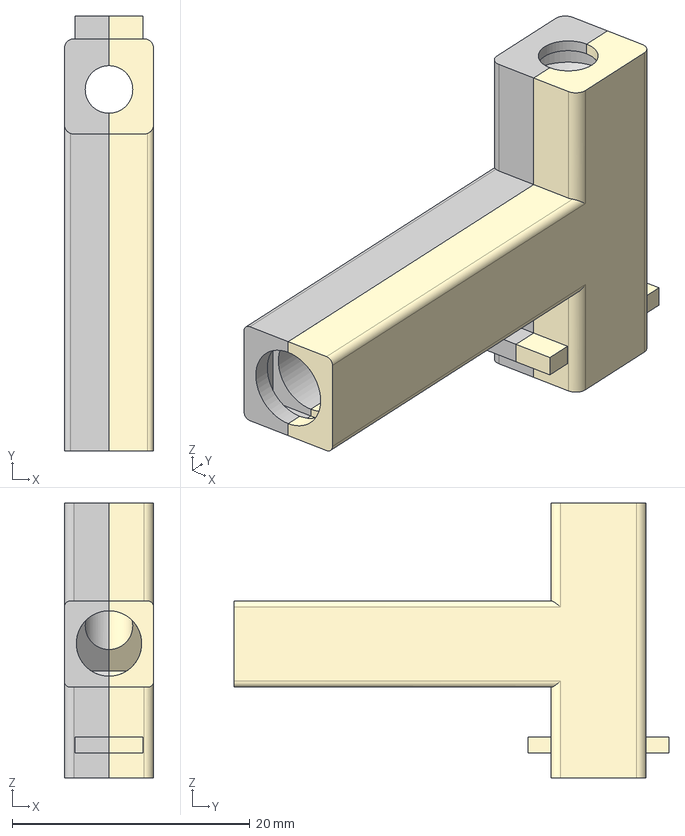
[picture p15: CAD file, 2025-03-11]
3D model/6.25 Detachable Double Planoconvex v2.step
7.50 x 36.6 x 23.1 mm

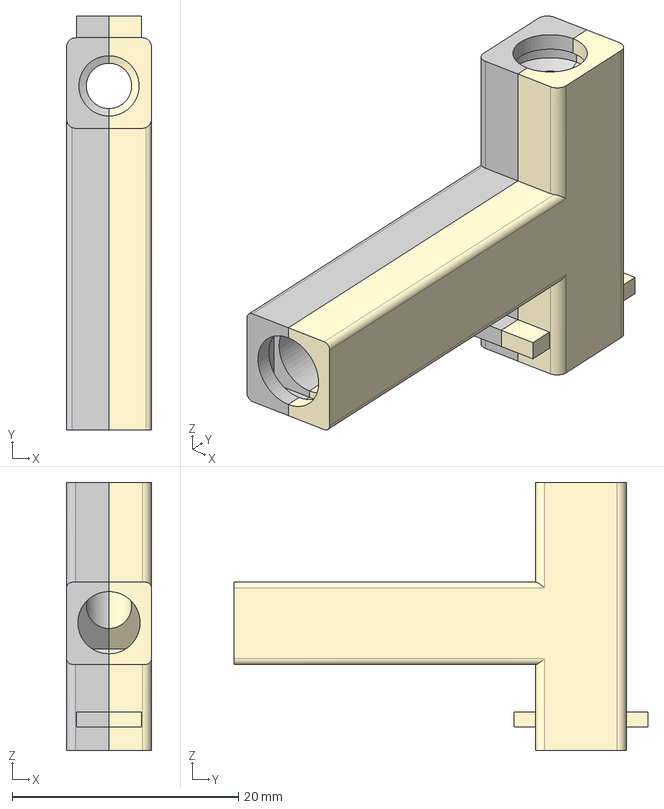
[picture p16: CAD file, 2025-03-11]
3D model/6.25 Detachable Triple Planoconvex_.step
7.50 x 36.6 x 23.7 mm

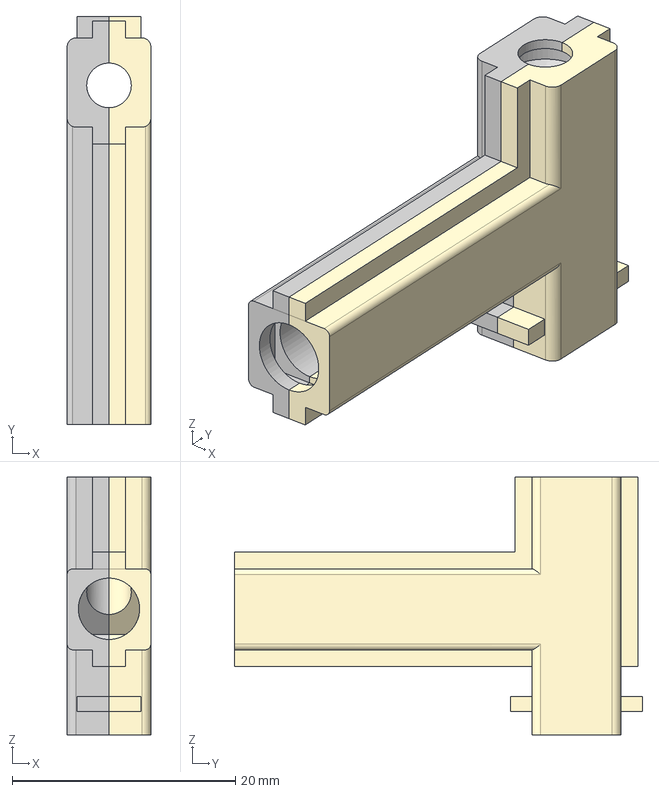
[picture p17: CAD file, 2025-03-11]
3D model/6.25 Detachable Double Planoconvex (Glue Variant) v2.step
7.50 x 36.6 x 23.1 mm

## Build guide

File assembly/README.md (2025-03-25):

# Miniscope Assembly Guide

This repository contains step-by-step instructions for assembling a complete miniscope. Follow the assembly process in the order outlined below.

## Assembly Order

### 1. [Resin Print Post-Processing](Resin-Print-Post-Proccessing.md) (Optional)
If you're 3D printing components yourself, follow these instructions to properly clean and prepare your printed parts before assembly.

### 2. [Optical Component Assembly](Optical-Component-Assembly.md)
Install all optical components including lenses, doublets, and filters into the main body of the miniscope.

### 3. [LED Installation](LED-Installation.md)
Assemble and install the LED PCB to provide illumination for the miniscope.

### 4. [CMOS Assembly](CMOS-Assembly.md)
Prepare and install the camera module (either MU196 or MU9) that will serve as the image sensor for your miniscope.

## Support
If you encounter any issues during assembly, please open an issue in this repository with detailed information about the problem.

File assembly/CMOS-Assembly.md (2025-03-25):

# CMOS Assembly and Installation Instructions

## ADPT-MU-CX3 Adapter Assembly Guide
This guide provides step-by-step instructions for disassembling the mu196 camera module and attaching the ADPT-MU-CX3 adapter.

## Required Components
- MU196 OR MU9 camera module
- MU196 OR MU9 housing mount
- ADPT-MU-CX3 adapter (MU196 only)
- CMOS specific printed mount
- Small Phillips screwdriver
- Clean, dust-free workspace

## MU196 Disassembly Steps (disregard if using the MU9)

### 1. Housing Removal
1. Identify the housing screws (located at corners of the gray housing)
2. Carefully remove all housing screws
3. Gently separate all housing from the assembly such that you are left with the exposed board level module

<p align="center">
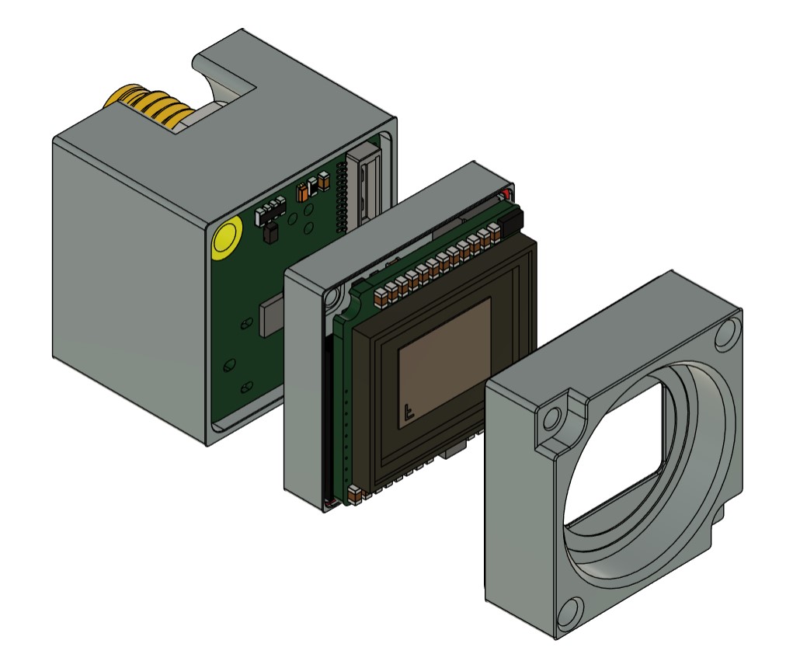
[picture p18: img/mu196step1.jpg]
  
</p>

### 2. Attachment
1. Align the ADPT-MU-CX3 adapter with the CMOS module
2. Carefully connect the adapter to the CMOS module

<p align="center">
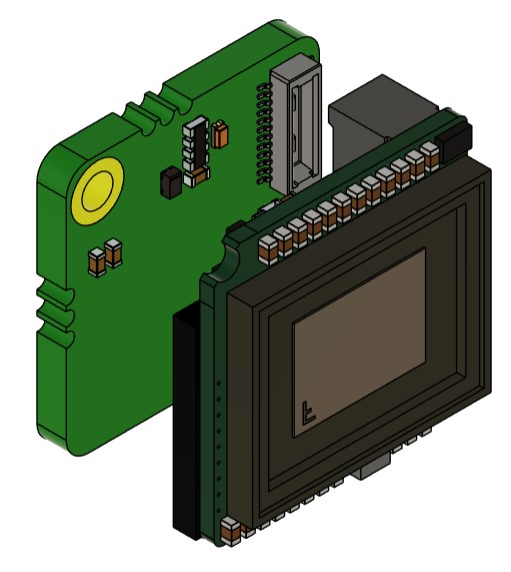
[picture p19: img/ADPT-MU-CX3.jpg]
  
</p>

## CMOS Installation
1. Simply place the camera module into its associated printed mount and slide the assembly onto the main mini-scope body

<p align="center">
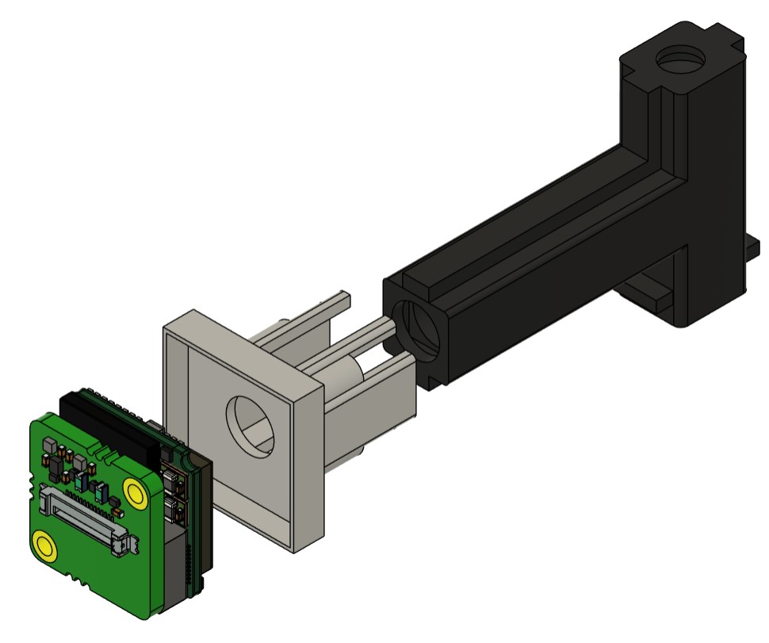
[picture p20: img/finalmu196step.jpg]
  
</p>

## Notes
- Handle the circuit board by its edges only
- Pay special attention to the orientation of components during reassembly
- If any components appear damaged, discontinue assembly and seek replacement parts

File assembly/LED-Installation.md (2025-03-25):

# Assembly - LED PCB

## Materials Needed
- LED PCB
- 2 LEDs
- Solder paste
- Soldering iron
- Black/Opaque electrical tape
- Wiring

## Assembly Steps

1. **Locate connection points**
   - Identify the ground, LED1 Vcc, and LED2 VCC pads on the PCB
   
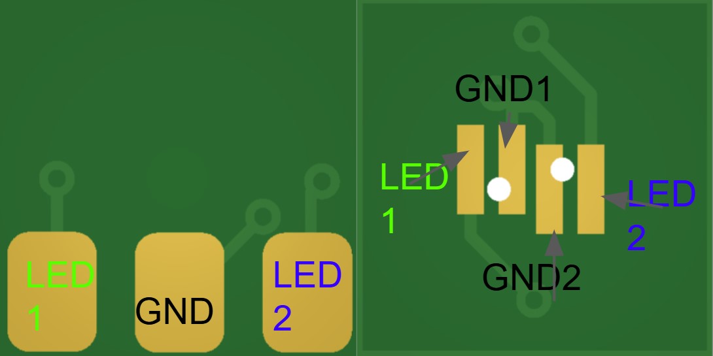
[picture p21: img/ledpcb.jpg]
PCB connection points
   

2. **Apply solder paste**
   - Apply solder paste to each LED pad
   - Be careful not to bridge each pad with the paste
   
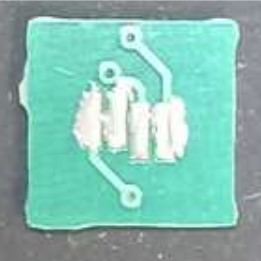
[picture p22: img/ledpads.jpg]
Solder paste application
   

3. **Position LEDs**
   - Gently place both LEDs into their respective positions
   - Apply slight pressure so they sink slightly into the solder

4. **Solder LEDs**
   - Apply heat to the PCB from the opposite side until solder is fully melted
   - Ensure both LEDs are properly settled in place

5. **Wire connections**
   - Once solder has solidified, flip the PCB to solder each wire according to the first diagram
   
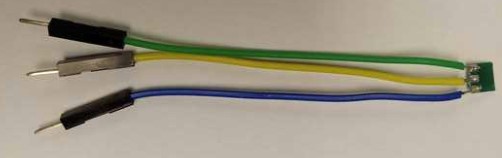
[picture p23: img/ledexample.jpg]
Wired PCB
   

6. **Final positioning**
   - Position the PCB face down so both LEDs shine through the exit port
   - Secure with Black/Opaque electrical tape

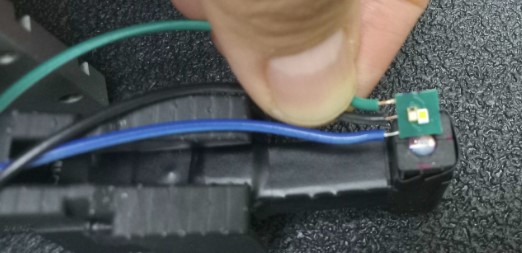
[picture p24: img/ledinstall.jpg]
Secured PCB
   

## Notes
- Ensure proper orientation of LEDs before soldering
- Verify all connections are secure before final assembly
- The black electrical tape helps prevent light leakage

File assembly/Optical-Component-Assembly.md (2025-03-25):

# Miniscope Assembly Instructions

## Required Components
Reference the Bill of Materials (BOM) for detailed part numbers and supplier information.

### Optical Components Needed
- 2× Plano-Convex Lens (O1)
- 1× 12.5mm FL Doublet (O3)
- 1× 60mm FL Doublet (O4)
- 1× Dichroic Filter (O7)
- 1× Excitation Filter - select either:
  - New design: ZET488/561x (O8) or
  - Previous design: 59022x (O9)
- 1× Emission Filter - select either:
  - New design: ZET488/561m (O5) or
  - Previous design: 59022m (O6)

### Housing Components Needed
- Main body (Y1)
- Lid body (Y2)

## Assembly Steps

### 1. Initial Preparation
- Clean all optical components with appropriate lens cleaning materials
- Verify all components are present and undamaged

<p align="center">
  Example preparation
</p>

### 2. Doublet Installation
1. Locate the excitation tower on the main body (Y1)
2. Install the pair of doublets in the excitation tower:
   - Position the 60mm FL doublet (O4) facing downwards, away from the excitation tower
   - Position the 12.5mm FL doublet (O3) facing upwards, toward the excitation tower

<p align="center">
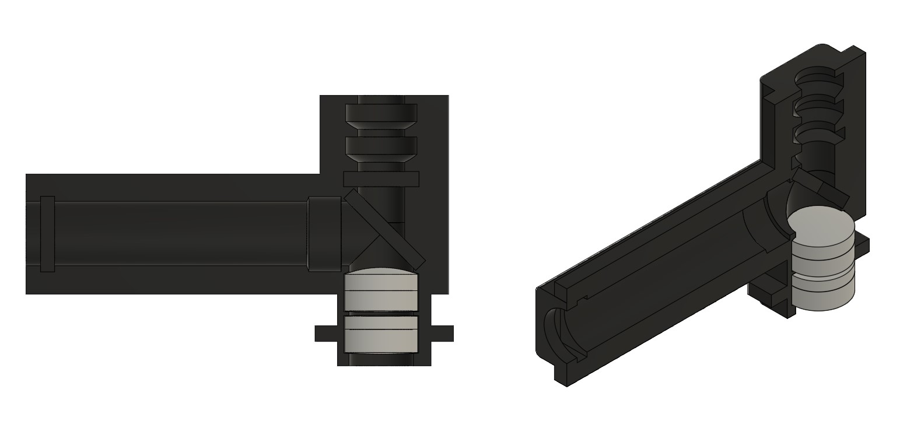
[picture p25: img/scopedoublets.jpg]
  
</p>

### 3. Filter Installation
1. Install the dichroic filter (O7)
   - Place in the excitation tower
   - **Important:** Reflective surface must face downwards, away from the excitation tower

2. Install the excitation filter (O8 or O9)
   - **Important:** Reflective surface must face the LED PCB (X1)

3. Install the emission filter (O5 or O6)
   - **Important:** Coating surface must face the excitation tower

<p align="center">
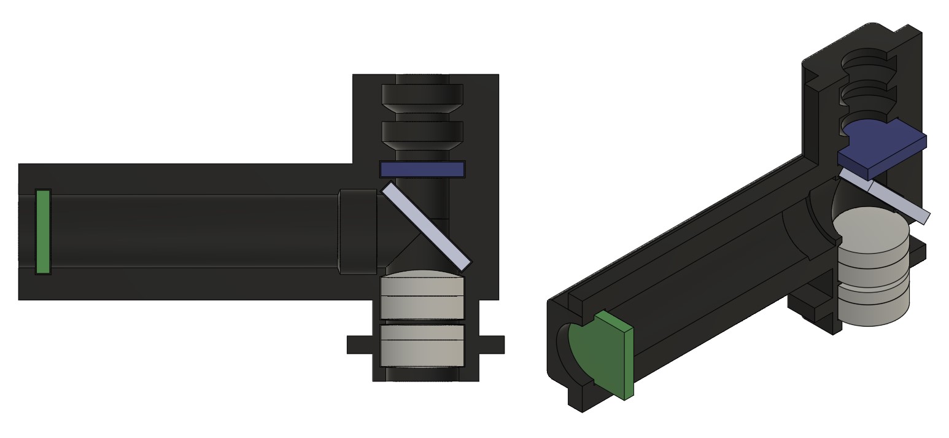
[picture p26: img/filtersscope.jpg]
  
</p>

### 4. Excitation Installation
1. Install the pair of Plano-Convex Lens (O1)
2. Install the final doublet lens (O2)

<div style="display: flex; justify-content: center; gap: 20px;">
  <div style="flex: 1; max-width: 45%;">
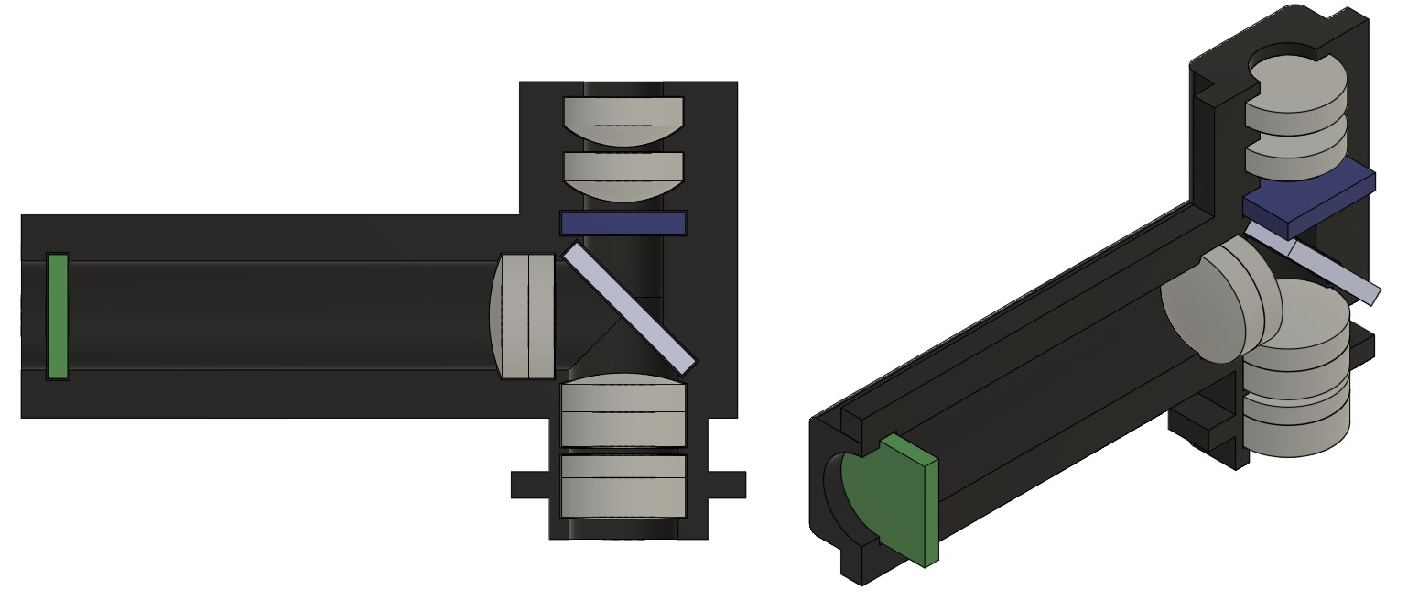
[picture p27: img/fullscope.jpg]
Before assembly
    
  </div>
  <div style="flex: 1; max-width: 45%;">
    Clamped scope
  </div>
</div>

### 5. Final Installation
1. Align the lid body (Y2) with the main body (Y1)
2. Place assembled unit in vise
   - Hold for 0.5-1 hour
3. Final sealing
   - Carefully apply appropriate adhesive to seal the main body (Y1) and lid body (Y2) together
   - Ensure alignment is maintained during sealing
<p align="center">
  Example preparation
</p>

## Important Notes
- **Filter Orientation:** Double-check all filter orientations before final assembly
- **Component Verification:** All optical components should be free of dust and fingerprints before assembly
- **Quality Control:** Verify all components are securely seated before final sealing
- **Documentation:** Record which filter set design was used in your build

## Component Care
- Handle all optical components by their edges only
- Use appropriate lens cleaning materials only
- Store unused components in their original packaging
- Keep work area clean and dust-free during assembly

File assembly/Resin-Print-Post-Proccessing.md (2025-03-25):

# Post-Processing Instructions

### Cleaning Printed Components

#### Required Materials
- Isopropyl alcohol
- Wire cutter or wedge
- Forceps
- Beaker
- Wash bottle with isopropyl alcohol
- Compressed air (optional)

#### Steps
1. **Printer Access**
   - Open printer hood
   - Lift inside latch above base plate

2. **Component Removal**
   - Remove base plate
   - Separate components using wire cutter or wedge
   - *Technique:* Lay wire cutter flat on base plate, squeeze into raft edges

3. **Initial Cleaning**
   - Place separated components in isopropyl alcohol vat

4. **Base Plate Cleaning**
   - Clean base plate with isopropyl alcohol
   - Clean all sides thoroughly
   - Return to printer and secure latch
   - *Note: Listen for audible latch confirmation*

5. **Detailed Component Cleaning**
   - Remove two components at a time using forceps
   - Suspend above beaker filled with isopropyl alcohol
   - Ensure components are submerged

6. **Centrifuge Cleaning**
   - Run centrifuge for 6 minutes total
   - Rotate components 180° after 3 minutes

7. **Final Cleaning**
   - Flush cavities with isopropyl alcohol wash bottle
   - Allow to dry naturally or use compressed air
   - Repeat if residual resin visible
   - *Note: Unwashed resin appears as non-drying liquid*

8. Repeat steps 5-7 for remaining components

### Painting Instructions

#### Required Materials
- Black paint
- Paint brush
- Paint tray

#### Steps
1. **Paint Preparation**
   - Pour small amount of black paint into tray

2. **Application**
   - Carefully paint miniscope interior
   - Avoid optical component cavities
   - Maintain clean edges

3. **Drying**
   - Allow to dry completely before installing optics
   - **Important:** Do not use compressed air to accelerate drying

## Safety Notes
- Work in well-ventilated area
- Wear appropriate PPE when handling isopropyl alcohol
- Dispose of waste materials properly
- Clean all work surfaces after use

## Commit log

2025-02-21 Added Bill of Materials
2025-02-21 Revised Bill of Materials
2025-02-21 Inital Assembly Setup
2025-02-21 Inital Assembly Setup v2
2025-03-11 Added reference material and files
    [6.25 Detachable Double Planoconvex (Glue Variant) v2.step, 6.25 Detachable Double Planoconvex v2.step, 6.25 Detachable Triple Planoconvex_.step]
2025-03-21 emission test
    [59022m.csv, ZET488561x.csv]
2025-03-25 updated assembly
2025-03-25 updated assembly v2
2025-03-25 assembly readme
2025-03-25 added mu9 holder stl
    [MU9-Holder.stl]
